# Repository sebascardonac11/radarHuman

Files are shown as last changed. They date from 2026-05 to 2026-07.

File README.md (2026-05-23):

# radarHuman

Detector de presencia humana con ESP8266-12F y sensor de radar HLK-LD2410B (24 GHz mmWave). Lee los frames UART del sensor y activa un relé cuando detecta presencia continua durante 500 ms. Instalación prevista en pared a 2,5 m de altura en exterior.

---

## Hardware

| Componente | Descripción |
|---|---|
| MCU | ESP8266-12F (160 MHz, 4 MB flash) |
| Sensor | HLK-LD2410B — radar 24 GHz mmWave, detección de movimiento y presencia estática |
| Actuador | Módulo relé 5 V con aislamiento óptico (entrada activa-baja) |
| Driver relé | Transistor NPN BC547 / 2N2222 + resistencia 1 kΩ |

## Conexiones

### LD2410B ↔ ESP8266-12F (SoftwareSerial)

| Pin sensor | GPIO ESP8266 | Pin WeMos D1 Mini | Función |
|---|---|---|---|
| TX | GPIO5 | D1 | Datos sensor → MCU (RX) |
| RX | GPIO14 | D5 | Comandos MCU → sensor (TX) |
| VCC | 3,3 V o 5 V | — | Alimentación |
| GND | GND | — | Tierra común |

### Relé (GPIO4 / D2)

```
GPIO4 ──[1 kΩ]── Base (BC547 / 2N2222)
                 Collector ── IN (módulo relé, activo-bajo)
                 Emitter  ── GND

GPIO4 HIGH  →  transistor ON  →  IN = LOW  →  relé energizado
GPIO4 LOW   →  transistor OFF →  IN = HIGH →  relé desenergizado
```

### Debug / monitor serie

UART0 (GPIO1 TX / GPIO3 RX) se usa para los logs de debug a 115 200 baud, accesible vía USB-serial.

---

## Funcionamiento

1. En `setup()`, `configureSensor()` abre SoftwareSerial a 256 000 baud (default de fábrica) y envía comandos al LD2410B para bajar el baud a 115 200 y reiniciarlo. Si el sensor ya está a 115 200, los comandos llegan corruptos y son ignorados — en ambos casos el sistema arranca en 115 200.
2. El parser de frames (`parseByte`) implementa una máquina de estados de 4 fases sobre el protocolo binario del LD2410B.
3. Cada frame (≈10 Hz) reporta el estado del objetivo en `frameBuf[8]`: `0x00` = ninguno, `0x01` = movimiento, `0x02` = estático, `0x03` = ambos.
4. Al detectar cualquier presencia (`state ≠ 0x00`), se registra `firstDetectedMs`. Tras 500 ms continuos de detección, el relé se activa.
5. `lastDetectedMs` se actualiza en cada frame con presencia. Si pasan 10 s sin detección, el relé se desactiva.

### Parámetros de tiempo

| Constante | Valor | Efecto |
|---|---|---|
| `CONFIRM_MS` | 2 000 ms | Presencia continua mínima para activar el relé |
| `HOLD_MS` | 2 000 ms | Ausencia sostenida para desactivar el relé |

---

## Protocolo UART LD2410B

Frame de reporte (23 bytes, ≈10 Hz):

```
F4 F3 F2 F1  |  0D 00  |  02  AA  [estado]  [dist_mov 2B]  [energía_mov]
[dist_est 2B]  [energía_est]  [dist_det 2B]  55  00  |  F8 F7 F6 F5
```

| Offset | Campo | Valor relevante |
|---|---|---|
| 0–3 | Header | `F4 F3 F2 F1` |
| 4–5 | Data length | `0D 00` (13 bytes) |
| 6 | Data type | `0x02` = reporte periódico |
| 7 | Head | `0xAA` |
| **8** | **Target state** | `0x00` sin objetivo / `≠0x00` presencia |
| 19–22 | End | `F8 F7 F6 F5` |

---

## Build y flash (PlatformIO)

```bash
# Compilar
pio run

# Compilar y flashear
pio run --target upload

# Monitor serie (si el botón de VSCode no responde, usar terminal)
~/.platformio/penv/bin/pio device monitor
```

Plataforma: `espressif8266`, board: `esp12e`, framework: `arduino`, CPU: 160 MHz. Solo se compila `src/main.cpp` (`build_src_filter = +<main.cpp>`).

---

## Documentación oficial

- Google Drive (datasheet, protocolo, herramienta de configuración BLE):
  https://drive.google.com/drive/folders/16zI-fium_BZeP08EyQke0rWp0BJTMvw3
- Protocolo serie detallado: `Doc/HLK-LD2410B human presence detection with BLE/LD2410B Serial communication protocol V1.07.pdf`
- Esquemático y PCB KiCad: `Doc/radarHuman/`

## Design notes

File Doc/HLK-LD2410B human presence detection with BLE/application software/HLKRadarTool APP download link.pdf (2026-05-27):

HLKRadarTool APP 下 | 载 | 链 | 接 | ：
https://www.hlktech.com/Mobile/App/12.html ios、安卓 都可通过此链接下载

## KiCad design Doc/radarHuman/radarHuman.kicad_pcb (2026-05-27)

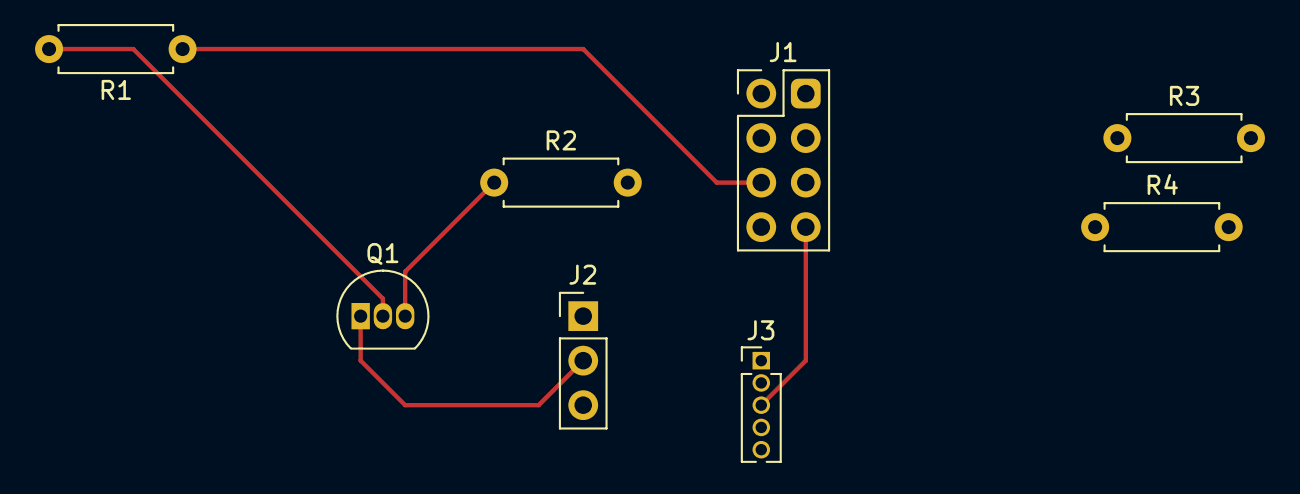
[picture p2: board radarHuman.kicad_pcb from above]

Board: 2 copper layers, 8 parts (0 on the bottom side), 12 nets.

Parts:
J1: ESP8266-01; PinHeader_2x04_P2.54mm_Vertical
J2: Rele; PinHeader_1x03_P2.54mm_Vertical
J3: LD2410B; PinHeader_1x05_P1.27mm_Vertical
Q1: BC547; TO-92_Inline
R1, R2, R3, R4: 1K; R_Axial_DIN0207_L6.3mm_D2.5mm_P7.62mm_Horizontal

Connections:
-3V3: J1.2, R3.2, R4.2
-5V: J2.3, J3.5
GND: J1.7, J2.1, J3.4, R2.2
unnamed: J1.4 (CH_EN), R3.1
unnamed: J1.5, R1.1
unnamed: J1.6 (Reset), R4.1
unnamed: J2.2, Q1.1 (C)
unnamed: Q1.2 (B), R1.2
unnamed: Q1.3 (E), R2.1
OUT: J1.3, J3.1
UART_RX: J1.8, J3.3
UART_TX: J1.1, J3.2

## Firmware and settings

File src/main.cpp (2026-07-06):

#include <Arduino.h>

#include "Config.h"
#include "RadarProtocol.h"
#include "RadarParser.h"
#include "PresenceRelay.h"
#include "WebPortal.h"

#define HEALTH_LOG_INTERVAL_MS 60000UL   // diagnóstico de heap, para detectar fugas en sesiones largas

namespace {
unsigned long lastHealthLogMs = 0;
}

void setup() {
    Serial.begin(115200);
    delay(200);
    Serial.println("=== BOOT OK ===");
    Serial.print("[SYS] razon de reinicio: ");
    Serial.println(ESP.getResetReason());

    PresenceRelay::begin();
    RadarProtocol::begin();   // baud rate + modo ingeniería del LD2410B
    WebPortal::begin();       // Access Point + servidor HTTP

    Serial.println("[RADAR] Esperando frames del LD2410B...");
}

void loop() {
    WebPortal::handleClient();

    while (radarSerial.available()) {
        RadarParser::feed(radarSerial.read());
        yield();   // feed ESP8266 watchdog and background tasks while draining buffer
    }
    RadarParser::tick();   // reset del parser si quedó atascado a mitad de frame

    PresenceRelay::update(RadarParser::telemetry().targetState);

    unsigned long now = millis();
    if (now - lastHealthLogMs >= HEALTH_LOG_INTERVAL_MS) {
        lastHealthLogMs = now;
        Serial.print("[SYS] uptime=");
        Serial.print(now / 1000);
        Serial.print("s heap=");
        Serial.print(ESP.getFreeHeap());
        Serial.print(" frag=");
        Serial.print(ESP.getHeapFragmentation());
        Serial.println("%");
    }
}

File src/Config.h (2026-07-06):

#pragma once

// ── Pines ──────────────────────────────────────────────────────────────────
#define RELAY_PIN     4   // GPIO4 — D2: NPN base via 1kΩ → relé activo-bajo
#define RADAR_RX_PIN  5   // GPIO5 — D1: ← LD2410B TX
#define RADAR_TX_PIN  14  // GPIO14 — D5: → LD2410B RX (necesario para configurar)

/*
  GPIO4 ──[1kΩ]── Base (BC547 / 2N2222)
                  Collector ── IN (módulo relé 5V, activo-bajo)
                  Emitter  ── GND
  GPIO4 HIGH → transistor ON → IN=LOW → relé ON
  GPIO4 LOW  → transistor OFF → IN=HIGH → relé OFF
*/

// ── Timing ─────────────────────────────────────────────────────────────────
#define RADAR_BAUD            115200UL
#define CONFIRM_MS            2000UL   // presencia continua antes de activar el relé
#define HOLD_MS                2000UL   // ausencia sostenida antes de apagar el relé
#define PARSER_TIMEOUT_MS      150UL    // reset del parser si un frame queda a medias
#define RADAR_ACK_TIMEOUT_MS   500UL    // espera máxima por un ACK de configuración

// ── Portal WiFi (modo Access Point) ───────────────────────────────────────
// El ESP crea su propia red — conéctate desde el celular/laptop y abre
// http://192.168.4.1/ para ver el estado del radar por gate y ajustar la
// sensibilidad (para filtrar falsos positivos por ramas, etc). Se mantiene
// activa siempre, como respaldo si el router de la finca no está disponible.
#define WIFI_AP_SSID  "RadarFinca"
#define WIFI_AP_PASS  "radar1234"   // mínimo 8 caracteres

// ── WiFi de la finca (modo estación) ──────────────────────────────────────
// Edita estos dos valores con el SSID/contraseña reales antes de flashear.
// El ESP se conecta también a esta red (además del AP de arriba), así que
// desde cualquier equipo ya conectado al WiFi de la finca podés entrar al
// portal con la IP que le asigne el router (se imprime por Serial al
// conectar) o directamente en http://radarhuman.local/ vía mDNS.
#define WIFI_STA_SSID  "Cardonas"
#define WIFI_STA_PASS  "Cardonas1234567890"
#define WIFI_STA_TIMEOUT_MS  15000UL   // tiempo máximo de espera al conectar
#define MDNS_HOSTNAME  "radarhuman"    // http://radarhuman.local/

#define GATE_COUNT  9

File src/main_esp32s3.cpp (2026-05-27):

#include <Arduino.h>

#define LED_PIN 2

void setup() {
    Serial.begin(115200);
    while (!Serial) delay(10); // espera a que el host abra el puerto CDC
    pinMode(LED_PIN, OUTPUT);
}

void loop() {
    Serial.println("Hola Mundo");
    digitalWrite(LED_PIN, HIGH);
    delay(500);
    digitalWrite(LED_PIN, LOW);
    delay(500);
}

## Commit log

2026-05-23 Firmware estable: SoftwareSerial 115200, configureSensor(), lógica relé con confirm/hold
    - configureSensor() configura el LD2410B a 115200 baud en cada boot (idempotente)
    - Parser de frames de 4 estados sobre protocolo binario del LD2410B
    - Relé activo tras 500 ms de presencia continua, se apaga tras 10 s de ausencia
    - Serial debug a 115200 por UART0 con estados y eventos del relé
    - platformio.ini: CPU 160 MHz, monitor_port y upload_port para /dev/cu.usbserial-145320
2026-05-23 Ajuste de tiempos: CONFIRM_MS y HOLD_MS a 2 s
2026-05-24 fix: recover from SoftwareSerial byte drops that caused permanent hang
    SoftwareSerial at 115200 baud loses bytes due to ESP8266 background task
    interrupts. When mid-frame bytes were lost the parser got stuck in RD_DATA
    or RD_END forever, consuming subsequent frames as garbage data.
    - Add parser timeout (150 ms): if a non-SYNC state receives no new byte,
    reset to SYNC so the next valid frame is processed normally
    - Call yield() between each byte read so the ESP8266 watchdog and SDK
    background tasks stay alive while draining the RX buffer
    - Throttle Serial state printing to only output on state change, reducing
    loop execution time and lowering the chance of buffer overruns
    https://clau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
    [main.cpp]
2026-05-24 Silenciar Serial prints para producción
2026-05-27 feat: agregar soporte ESP32-S3, documentación hardware y esquemáticos KiCad
    - Nuevo env esp32s3 en platformio.ini con flags USB CDC/native
    - src/main_esp32s3.cpp: variante del firmware para ESP32-S3
    - src/radarHuman/radarHuman.ino: prototipo archivado ESP-01 (excluido del build)
    - Doc/: datasheet BC547, pinout ESP8266, protocolo serial LD2410B, esquemáticos y PCB KiCad
    - .gitignore: excluir .DS_Store
    [radarHuman.kicad_pcb, radarHuman.kicad_sch]
2026-07-06 Generacion de web para identificar gates y wave publicado en una en el wifi de la fiinca o en el del esp
